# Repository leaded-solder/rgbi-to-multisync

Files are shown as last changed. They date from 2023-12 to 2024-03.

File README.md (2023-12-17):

# NEC MultiSync MDA/CGA/EGA/Japanese DIN RGBI adapter
This adapter is meant to help support multiple old computers when used with the NEC MultiSync line of CRTs.

It has only been tested on the MultiSync 3D. Earlier models may require a different adapter; please check your service manual.

# Current Status
**NOT WORKING** - the MultiSync does not wake up under Japanese RGBI input from either a PC-6601SR or PC-9801UV2.

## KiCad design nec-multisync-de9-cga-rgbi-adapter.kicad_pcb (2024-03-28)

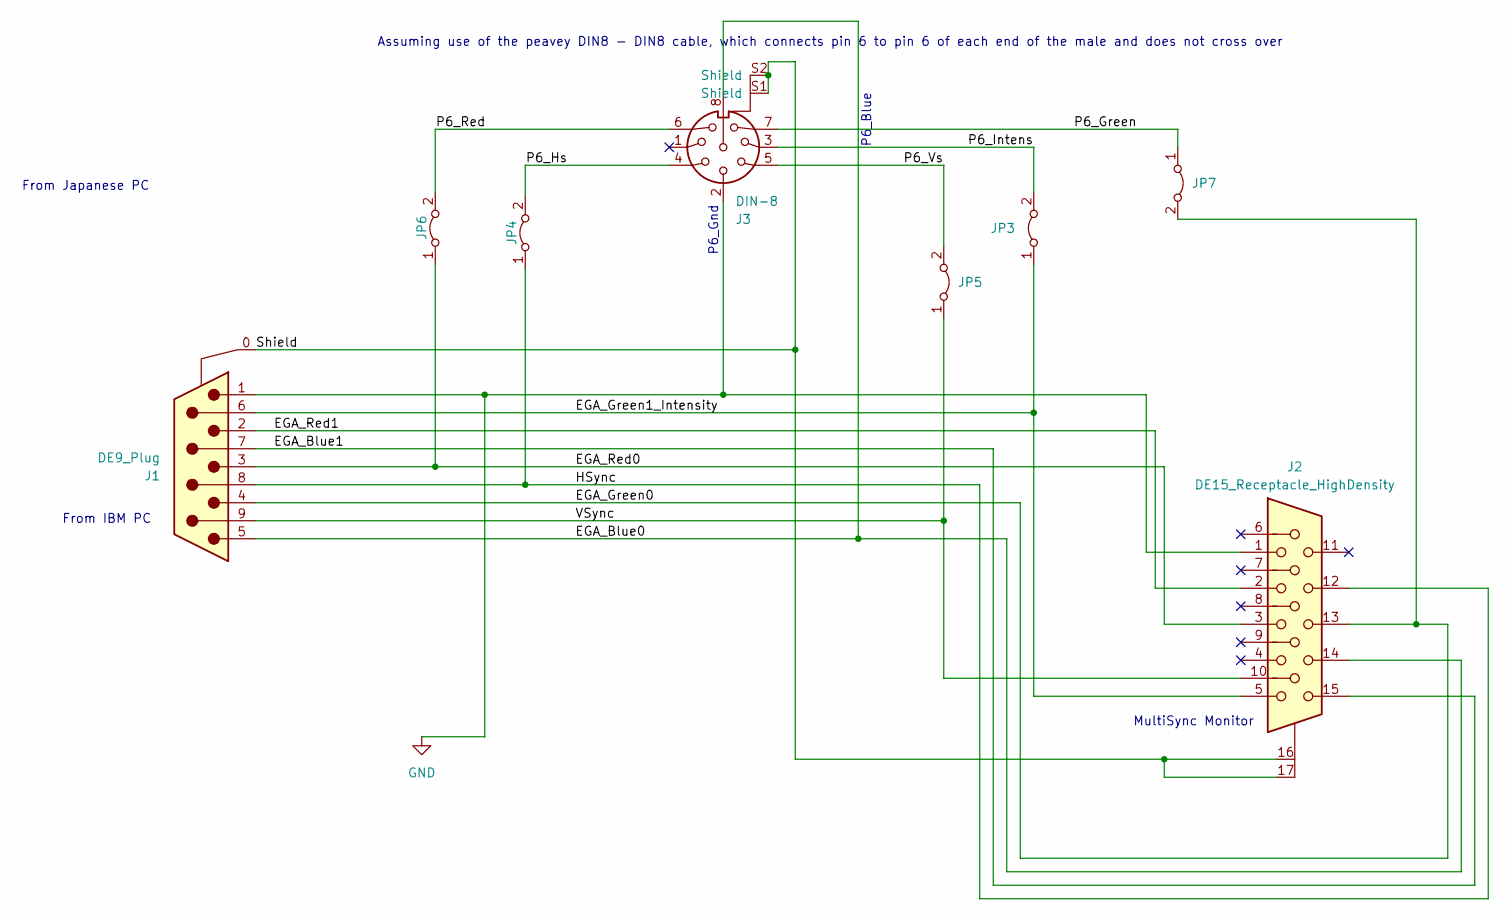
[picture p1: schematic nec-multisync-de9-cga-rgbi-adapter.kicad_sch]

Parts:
J1: DE9_Plug; DSUB-9_Male_Horizontal_P2.77x2.84mm_EdgePinOffset7.70mm_Hou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
J2: DE15_Receptacle_HighDensity; FIXED-1-1734530-1
J3: DIN-8; CUI_SDS-80J
JP3, JP4, JP5, JP6, JP7: Jumper_2_Bridged; SolderJumper-2_P1.3mm_Bridged_Pad1.0x1.5mm

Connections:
/EGA_Blue0: J1.5, J2.14, J3.8
/EGA_Blue1: J1.7, J2.15
/EGA_Green0: J1.4, J2.13, JP7.2 (B)
/EGA_Green1_Intensity: J1.6, J2.5, JP3.1 (A)
/EGA_Red0: J1.3, J2.3, JP6.1 (A)
/EGA_Red1: J1.2, J2.2
/HSync: J1.8, J2.12, JP4.1 (A)
/P6_Green: J3.7, JP7.1 (A)
/P6_Hs: J3.4, JP4.2 (B)
/P6_Intens: J3.3, JP3.2 (B)
/P6_Red: J3.6, JP6.2 (B)
/P6_Vs: J3.5, JP5.2 (B)
/Shield: J1.0 (Shield), J2.16 (Shield), J2.17 (Shield), J3.S1 (Shield), J3.S2 (Shield)
/VSync: J1.9, J2.10, JP5.1 (A)
GND: J1.1, J2.1, J3.2

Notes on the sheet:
MultiSync Monitor
P6_Blue
P6_Gnd
From Japanese PC
Assuming use of the peavey DIN8 - DIN8 cable, which connects pin 6 to pin 6 of each end of the male and does not cross over
From IBM PC

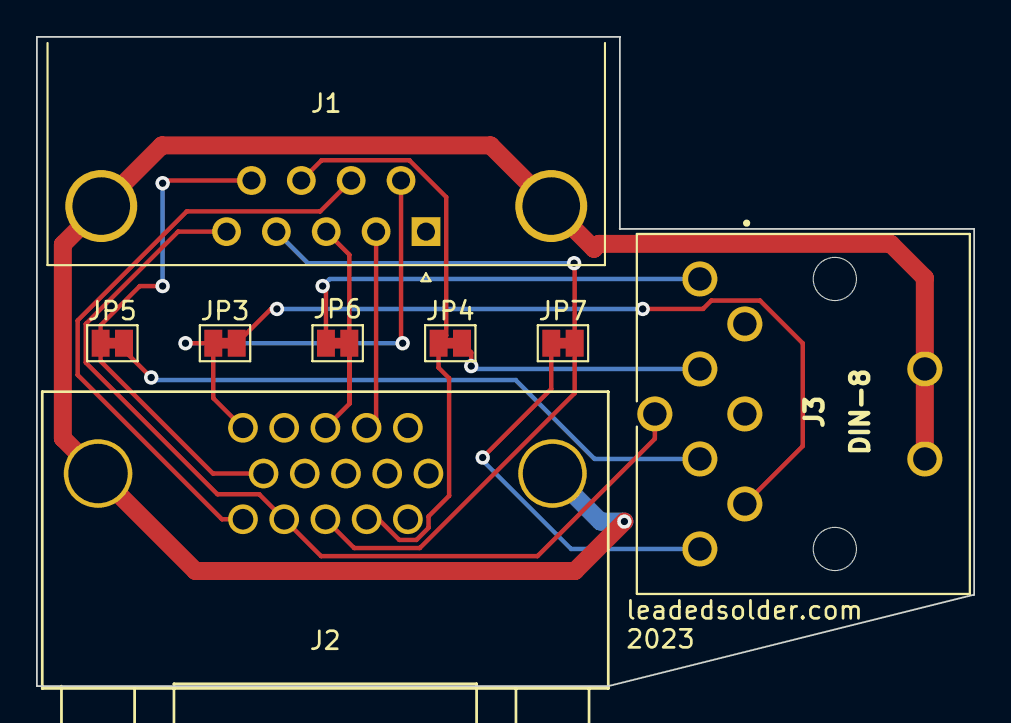
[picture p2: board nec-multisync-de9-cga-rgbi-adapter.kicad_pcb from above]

Board: 2 copper layers, 52.1 x 36.1 mm, 8 parts (0 on the bottom side), 15 nets.

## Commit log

2023-11-27 initial commit, starting out
    [nec-multisync-de9-cga-rgbi-adapter.kicad_pcb, nec-multisync-de9-cga-rgbi-adapter.kicad_sch]
2023-11-27 V1 to Fab
    [nec-multisync-de9-cga-rgbi-adapter.kicad_pcb, nec-multisync-de9-cga-rgbi-adapter.kicad_sch]
2023-12-17 Remove annoying tab that fouls on Tandy
    [nec-multisync-de9-cga-rgbi-adapter.kicad_pcb]
2023-12-17 Update to NOTWORKING
    [nec-multisync-de9-cga-rgbi-adapter.kicad_sch]
2023-12-18 Artistic label placement
    [nec-multisync-de9-cga-rgbi-adapter.kicad_pcb]
2023-12-18 Maybe reverse my bonehead fuckup of feeding 12V to the MultiSync's signal input
    [nec-multisync-de9-cga-rgbi-adapter.kicad_pcb, nec-multisync-de9-cga-rgbi-adapter.kicad_sch]
2023-12-18 Label nets
    [nec-multisync-de9-cga-rgbi-adapter.kicad_pcb, nec-multisync-de9-cga-rgbi-adapter.kicad_sch]
2023-12-18 Prepare to flip DIN
    [nec-multisync-de9-cga-rgbi-adapter.kicad_pcb, nec-multisync-de9-cga-rgbi-adapter.kicad_sch]
2023-12-18 World's ugliest reroute
    [nec-multisync-de9-cga-rgbi-adapter.kicad_pcb, nec-multisync-de9-cga-rgbi-adapter.kicad_sch]
2023-12-18 Tie shield pins to ground
    [nec-multisync-de9-cga-rgbi-adapter.kicad_pcb]
2023-12-18 V2 (flipped, DE9 interference fixed) sent to fab
    [nec-multisync-de9-cga-rgbi-adapter.kicad_pcb]
2024-03-28 Tie shields together
    [nec-multisync-de9-cga-rgbi-adapter.kicad_pcb, nec-multisync-de9-cga-rgbi-adapter.kicad_sch]

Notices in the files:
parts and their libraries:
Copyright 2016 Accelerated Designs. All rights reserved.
